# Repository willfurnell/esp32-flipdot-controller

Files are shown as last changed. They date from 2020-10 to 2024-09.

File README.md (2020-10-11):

# `esp32-flipdot-controller`

## Replacement controller for Hannover Flipdot Displays

This is a fork of the original https://github.com/themainframe/esp32-flipdot-controller, but is designed to allow for more than one panel (my display has three), and works with the Platform.IO build, and Arduino ecosystems.

It currently gets the time from an NTP server and displays it. The code obviosuly needs more work, but it's good enough for now. 

Also included in this repository are KiCad schematics for my version of the PCB, which has hardware (but not yet software) support for the built in LED strip and other personal customisations.

Based on the [blog post on damow.net](https://damow.net/fun-with-flip-dot-displays/)!

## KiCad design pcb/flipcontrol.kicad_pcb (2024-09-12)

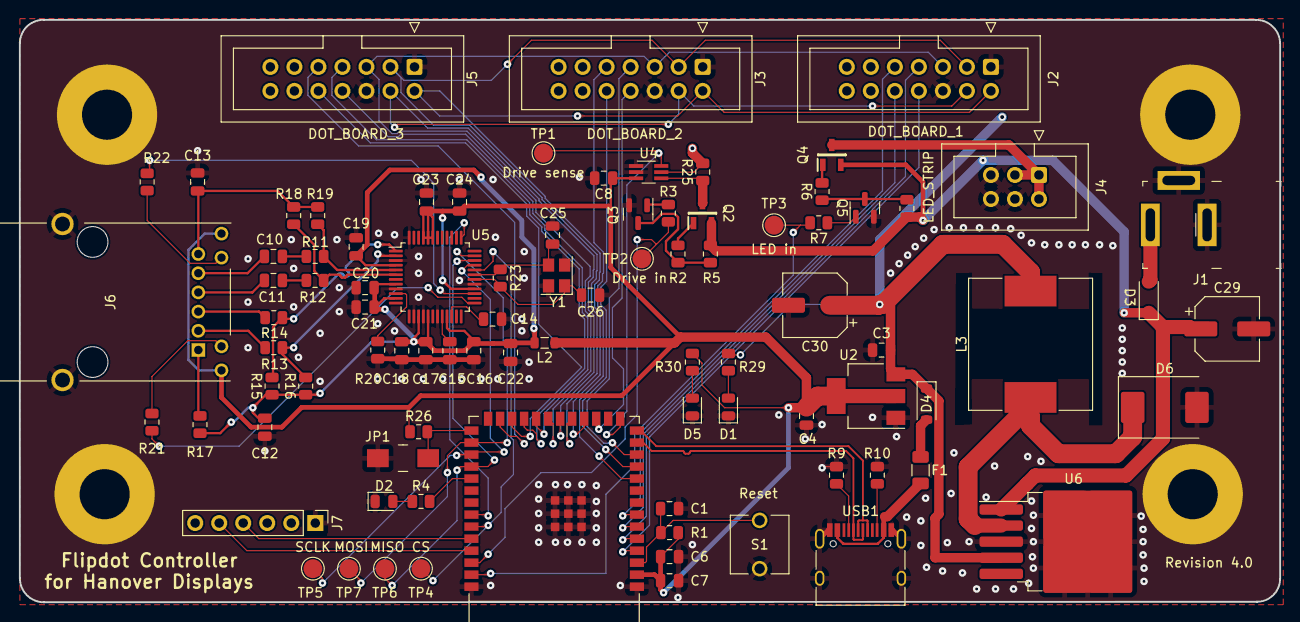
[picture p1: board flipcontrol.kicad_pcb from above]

Board: 4 copper layers, 133.3 x 61.6 mm, 92 parts (0 on the bottom side), 75 nets.

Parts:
C1, C6, C8: 100nF; C_0805_2012Metric
C3, C4, C7, C22, C23: 10uF; C_0805_2012Metric
C10, C11: 6.8nF; C_0805_2012Metric
C12: 22nF; C_0805_2012Metric
C13, C14: 10nF; C_0805_2012Metric
C15: 4.7uF; C_0805_2012Metric
C16, C17, C18, C19, C20, C21, C24: 0.1uF; C_0805_2012Metric
C25, C26: 18pF; C_0805_2012Metric
C29: 100uF; CP_Elec_6.3x5.4
C30: 330uF; CP_Elec_6.3x5.4
D1: 5V; LED_0805_2012Metric
D2: ESP_LED; LED_0805_2012Metric
D3, D4: D; D_SOD-123
D5: 3V3; LED_0805_2012Metric
D6: 700mV 5A; D_SMC
F1: Polyfuse; Fuse_1206_3216Metric
H1, H2, H3, H4: MountingHole_Pad; MountingHole_5.3mm_M5_Pad
J1: PJ-202A; Barrel_Jack_5.5mmODx2.1mmID_PJ-202A
J2: DOT_BOARD_1; IDC-Header_2x07_P2.54mm_Vertical
J3: DOT_BOARD_2; IDC-Header_2x07_P2.54mm_Vertical
J4: LED_STRIP; IDC-Header_2x03_P2.54mm_Vertical
J5: DOT_BOARD_3; IDC-Header_2x07_P2.54mm_Vertical
J6: RJMG163118101NR
J7: FTDI; PinHeader_1x06_P2.54mm_Vertical
JP1: Bootloader; Jumper_Tin_P5.32mm
L2: 120Ohms@100MHz; L_0805_2012Metric
L3: 47uH; L_Sunlord_MWSA1206S-470
Q2, Q4: Si2347DS-T1-GE3; SOT95P237X112-3N
Q3, Q5: MMBT3904; SOT-23
R1, R3, R5, R7, R8, R26: 10K; R_0805_2012Metric
R2, R6: 100R; R_0805_2012Metric
R4: 2K; R_0805_2012Metric
R9, R10: 5.1K; R_0805_2012Metric
R11, R12, R13, R14: 33R; R_0805_2012Metric
R15, R16, R18, R19: 49R9; R_0805_2012Metric
R17: 10R; R_0805_2012Metric
R20: 12.4k; R_0805_2012Metric
R21, R22: 330R; R_0805_2012Metric
R23: 1M; R_0805_2012Metric
R25: 0.015 R; R_0805_2012Metric
R29: 145R; R_0805_2012Metric
R30: 60R; R_0805_2012Metric
S1: RESET; FSM2JRT
TP1: Drive sense; TestPoint_Pad_D2.0mm
TP2: Drive in; TestPoint_Pad_D2.0mm
TP3: LED in; TestPoint_Pad_D2.0mm
TP4: CS; TestPoint_Pad_D2.0mm
TP5: SCLK; TestPoint_Pad_D2.0mm
TP6: MISO; TestPoint_Pad_D2.0mm
TP7: MOSI; TestPoint_Pad_D2.0mm
U2: AMS1117-3.3; SOT-223-3_TabPin2
U3: ESP32-S3-WROOM-1
U4: NCS214; SOT-363_SC-70-6_Handsoldering
U5: W5500; LQFP-48_7x7mm_P0.5mm
U6: LM2596S-5; TO-263-5_TabPin3
USB1: HRO-TYPE-C-31-M-12; USB_C_Receptacle_HRO_TYPE-C-31-M-12
Y1: Crystal_GND24; Crystal_SMD_Abracon_ABM8G-4Pin_3.2x2.5mm

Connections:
+3.3VA: C12.1, C16.1, C17.1, C18.1, C19.1, C20.1, C21.1, C22.1, L2.2, R15.1, R16.1, R17.2, U5.4 (AVDD), U5.8 (AVDD), U5.11 (AVDD), U5.15 (AVDD), U5.17 (AVDD), U5.21 (AVDD)
+3V3: C4.1, C6.2, C7.1, C8.1, C23.1, C24.1, J6.L1 (GREEN_A_1), J6.L4 (GREEN_A_2), L2.1, R1.1, R26.1, R30.1, U2.2 (VO), U3.2 (3V3), U4.3 (Vs), U5.28 (VDD), U5.43 (PMODE2), U5.44 (PMODE1), U5.45 (PMODE0)
+5V: C3.1, C30.1, D4.1 (K), J2.11, J3.11, J5.11, L3.2, R29.1, U2.3 (VI), U6.4 (FB)
+18V: C29.1, D3.1 (K), J2.14, J3.14, J5.14, Q2.2 (S), Q4.2 (S), R5.1, R8.1, U6.1 (VIN)
ACT_LED: R22.2, U5.27 (ACTLED)
COIL_DRIVE_IN: R3.2, TP2.1, U3.38 (GPIO2/TOUCH2/ADC1_CH1)
COIL_DRIVE_OUT: J2.12, J2.13, J3.12, J3.13, J5.12, J5.13, R25.2, U4.5 (-IN)
COIL_DRIVE_SENSE: TP1.1, U3.15 (GPIO3/TOUCH3/ADC1_CH2), U4.6 (OUT)
COL_ADVANCE_1: J2.7, U3.5 (GPIO5/TOUCH5/ADC1_CH4)
COL_ADVANCE_2: J3.7, U3.12 (GPIO8/TOUCH8/ADC1_CH7/SUBSPICS1)
COL_ADVANCE_3: J5.7, U3.23 (GPIO21)
CS: TP4.1, U3.35 (MTMS/GPIO42), U5.32 (~SCS)
EN: C1.1, R1.2, S1.2, U3.3 (EN)
ENABLE_1: J2.2, J3.2, J5.2, U3.18 (GPIO10/TOUCH10/ADC1_CH9/FSPICS0/FSPIIO4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)
ENABLE_2: J2.3, J3.3, J5.3, U3.19 (GPIO11/TOUCH11/ADC2_CH0/FSPID/FSPIIO5/S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)
ENABLE_3: J2.4, J3.4, J5.4, U3.20 (GPIO12/TOUCH12/ADC2_CH1/FSPICLK/FSPIIO6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)
ENABLE_4: J2.5, J3.5, J5.5, U3.21 (GPIO13/TOUCH13/ADC2_CH2/FSPIQ/FSPIIO7/S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)
ESP_LED: R4.2, U3.31 (GPIO38/FSPIWP/SUBSPIWP)
ESP_RXD: J7.4, U3.36 (U0RXD/GPIO44/CLK_OUT2)
ESP_TXD: J7.5, U3.37 (U0TXD/GPIO43/CLK_OUT1)
ETH_RST: U3.34 (MTDI/GPIO41/CLK_OUT1), U5.37 (~RST)
ETH_RXN: R11.1, R19.1, U5.5 (RXN)
ETH_RXP: R12.2, R18.1, U5.6 (RXP)
ETH_TXN: R14.1, R15.2, U5.1 (TXN)
ETH_TXP: R13.1, R16.2, U5.2 (TXP)
GND: C1.2, C3.2, C4.2, C6.1, C7.2, C8.2, C12.2, C13.2, C14.1, C15.1, C16.2, C17.2, C18.2, C19.2, C20.2, C21.2, C22.2, C23.2, C24.2, C25.2, C26.2, C29.2, C30.2, D1.1 (K), D2.1 (K), D5.1 (K), D6.2 (A), H1.1, H2.1, H3.1, H4.1, J1.2, J1.3, J2.1, J2.6, J3.1, J3.6, J4.4, J4.5, J4.6, J5.1, J5.6, J6.S1, J6.S2, J7.1, JP1.1 (A), Q3.2 (E), Q5.2 (E), R9.1, R10.1, R20.2, S1.1, U2.1 (GND), U3.1 (GND), U3.40 (GND), U3.41 (GND), U4.1 (REF), U4.2 (GND), U5.3 (AGND), U5.9 (AGND), U5.14 (AGND), U5.16 (AGND), U5.19 (AGND), U5.29 (GND), U5.48 (AGND), U6.3 (GND), USB1.A1 (GND), USB1.A12 (GND), USB1.B1 (GND), USB1.B12 (GND), USB1.S1 (SHIELD), Y1.2, Y1.4
IO0: JP1.2 (B), R26.2, U3.27 (GPIO0/BOOT)
LED_IN: R7.2, TP3.1, U3.39 (GPIO1/TOUCH1/ADC1_CH0)
LED_OUT: J4.1, J4.2, J4.3, Q4.3 (D)
LINK_LED: R21.2, U5.25 (LINKLED)
MISO: TP6.1, U3.30 (SPIDQS/GPIO37/FSPIQ/SUBSPIQ), U5.34 (MISO)
MOSI: TP7.1, U3.28 (SPIIO6/GPIO35/FSPID/SUBSPID), U5.35 (MOSI)
unnamed: C10.2, R11.2
unnamed: C11.1, R12.1
unnamed: D1.2 (A), R29.2
unnamed: D2.2 (A), R4.1
unnamed: D3.2 (A), J1.1
unnamed: D4.2 (A), F1.2
unnamed: D5.2 (A), R30.2
unnamed: D6.1 (K), L3.1, U6.2 (OUT)
unnamed: J6.L2 (GREEN_K_1), R21.1
unnamed: J6.L3 (GREEN_K_2), R22.1
unnamed: C13.1, J6.R6 (RCT), R18.2, R19.2
unnamed: C11.2, J6.R4 (RX+)
unnamed: C10.1, J6.R5 (RX-)
unnamed: J6.R1 (TCT), R17.1
unnamed: J6.R2 (TX+), R13.2
unnamed: J6.R3 (TX-), R14.2
unnamed: Q2.3 (D), R25.1, U4.4 (+IN)
unnamed: Q2.1 (G), R2.2
unnamed: Q3.1 (B), R3.1
unnamed: Q3.3 (C), R2.1, R5.2
unnamed: Q4.1 (G), R6.2
unnamed: Q5.1 (B), R7.1
unnamed: Q5.3 (C), R6.1, R8.2
unnamed: C14.2, U5.22 (1V2O)
unnamed: R20.1, U5.10 (EXRES1)
unnamed: C15.2, U5.20 (TOCAP)
unnamed: C26.1, R23.2, U5.30 (XI/CLKIN), Y1.1
unnamed: C25.1, R23.1, U5.31 (XO), Y1.3
unnamed: R9.2, USB1.A5 (CC1)
unnamed: R10.2, USB1.B5 (CC2)
RESET_1: J2.8, U3.4 (GPIO4/TOUCH4/ADC1_CH3)
RESET_2: J3.8, U3.17 (GPIO9/TOUCH9/ADC1_CH8/FSPIHD/SUBSPIHD)
RESET_3: J5.8, U3.22 (GPIO14/TOUCH14/ADC2_CH3/FSPIWP/FSPIDQS/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)
ROW_ADVANCE_1: J2.10, U3.6 (GPIO6/TOUCH6/ADC1_CH5)
ROW_ADVANCE_2: J3.10, U3.11 (GPIO18/U1RXD/ADC2_CH7/CLK_OUT3)
ROW_ADVANCE_3: J5.10, U3.24 (GPIO47/SPICLK_P/SUBSPICLK_P_DIFF)
SCLK: TP5.1, U3.29 (SPIIO7/GPIO36/FSPICLK/SUBSPICLK), U5.33 (SCLK)
SET_UNSET_1: J2.9, U3.7 (GPIO7/TOUCH7/ADC1_CH6)
SET_UNSET_2: J3.9, U3.10 (GPIO17/U1TXD/ADC2_CH6)
SET_UNSET_3: J5.9, U3.25 (GPIO48/SPICLK_N/SUBSPICLK_N_DIFF)
USB_DN: U3.13 (GPIO19/U1RTS/ADC2_CH8/CLK_OUT2/USB_D-), USB1.A7 (D-), USB1.B7 (D-)
USB_DP: U3.14 (GPIO20/U1CTS/ADC2_CH9/CLK_OUT1/USB_D+), USB1.A6 (D+), USB1.B6 (D+)
USB_VBUS: F1.1, USB1.A4 (VBUS), USB1.A9 (VBUS), USB1.B4 (VBUS), USB1.B9 (VBUS)

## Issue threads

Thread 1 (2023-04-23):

Drive current measurement

russss, 2023-04-23:
During initialisation, the original Hanover controller detects the size of display by flipping dots along a row and a column and (presumably) measuring the drive current to detect where the display ends.

Replicating this is a bit frivolous - you could just store the size of the display in flash - but it's kind of cool and I'd like to try and emulate it.

(I wonder if this might actually provide a way of speeding up refresh rates, if you could use the current draw to detect when the dot has been flipped?)

I think this just needs a current shunt resistor in the drive line, and then an op-amp (which can be optional) and an ADC channel.

Closed 2023-05-11.

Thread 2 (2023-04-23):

Ethernet support

russss, 2023-04-23:
I'd like wired ethernet support for using these displays at events. I'm a bit wary of using wifi especially when the ESP32 is in a metal box.

If we're using the ESP32-S3 then it sounds like we need an SPI MAC/PHY for this. The throughput should be pretty minimal so hopefully this won't be an issue.

All the ethernet stuff should be optional.

willfurnell, 2023-05-06:
I have added this to the schematic

Closed 2023-05-11.

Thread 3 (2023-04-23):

LED strip driving thoughts

russss, 2023-04-23:
Two things:

1) I have a suspicion that these flipdots would look pretty good under UV lighting. Maybe we should have provision for driving multiple independent channels of LED so that I can fit a combined white and UV strip and pick a colour.

2) Is the stock Hanover LED strip driven at 18V or 24V? 24V is a standard voltage for non-addressable LED strip, so if we retrofit strip it's going to be under-driven at 18V. Some of the LEDs in our signs are looking a bit crap and could do with replacement, so this doesn't solely affect my UV plans. We should check the voltage of the stock Hanover strip, and if it's 18V we should check how well 24V strip performs at that voltage.

russss, 2023-04-28:
The plot thickens, I've just checked the LED voltage in our smallest flipdot and it's running at 16V...

willfurnell, 2023-05-06:
As per discussion on Slack - 16V is a pain - probably going to ignore the LED strips on the first revision. Why would they do this...?!

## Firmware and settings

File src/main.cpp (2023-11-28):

#include <stdlib.h>
#include <stdint.h>
#include <unistd.h>
#include <string.h>
#include "esp_log.h"
#include "WiFi.h"
#include "flipdot.h"
#include "fill.h"
#include "main.h"
#include "scroll.h"
#include "text.h"
#include <WiFiUdp.h>
#include "NTP.h"
#include <ESPmDNS.h>
#include "graphics.h"

static const char *TAG = "Main";

const char *ssid = "NoConnection";
const char *password = "";
const char *host = "flipdot";

WiFiUDP ntpUDP;
NTP ntp(ntpUDP);

dotboard_t dots;

void setup()
{
    ESP_LOGI(TAG, "Flipdot Display Controller System startup");

    // Initialise display
    flipdot_init();

    fill_on(&dots);
    write_dotboard(&dots, true);
    fill_off(&dots);
    write_dotboard(&dots, true);
    render_text_4x5(&dots, 0, 1, "Connecting...");
    write_dotboard(&dots, true);

    // Init wifi

    WiFi.begin(ssid, password);

    while (WiFi.status() != WL_CONNECTED)
    {
        vTaskDelay(500 / portTICK_RATE_MS);
    }

    if (!MDNS.begin(host))
    {
        ESP_LOGE("Error setting up MDNS responder!");
        while (1)
        {
            vTaskDelay(1000 / portTICK_RATE_MS);
        }
    }
    fill_off(&dots);
    render_text_4x5(&dots, 0, 1, WiFi.localIP().toString().c_str());
    write_dotboard(&dots, true);
    vTaskDelay(2000 / portTICK_RATE_MS);

    //fill_off(&dots);
    //write_dotboard(&dots, true);

    // Set up summer time rules
    ntp.ruleDST("BST", Last, Sun, Mar, 1, 60);
    ntp.ruleSTD("GMT", Last, Sun, Oct, 2, 0);
    ntp.begin();

    fill_off(&dots);
    render_text_4x5(&dots, 0, 1, ntp.formattedTime("%a %d %b %H:%M"));
    write_dotboard(&dots, true);
}

void loop()
{
    ntp.update();
    //fill_on(&dots);
    //fill_off(&dots);
    //render_text_4x5(&dots, 0, 1, "PARTAYYYYYYYYY");
    //write_dotboard(&dots, false);
    //vTaskDelay(10000 / portTICK_RATE_MS);
    //fill_off(&dots);
    //render_text_4x5(&dots, 0, 1, "HAPPY BIRTHDAY!");
    //write_dotboard(&dots, false);
    //vTaskDelay(10000 / portTICK_RATE_MS);
    //fill_off(&dots);
    //render_text_4x5(&dots, 0, 1, "LAURA AND MEGAN");
    //write_dotboard(&dots, false);
    //vTaskDelay(10000 / portTICK_RATE_MS);
    fill_off(&dots);
    render_text_4x5(&dots, 0, 1, ntp.formattedTime("%a %d %b %H:%M"));
    write_dotboard(&dots, false);
    //scroll_update();
    vTaskDelay(20000 / portTICK_RATE_MS);
    fill_off(&dots);
    render_cyberman(&dots, 0);
    render_cyberman(&dots, 9);
    render_cyberman(&dots, 18);
    render_cyberman(&dots, 27);
    render_cyberman(&dots, 36);
    render_cyberman(&dots, 45);
    render_cyberman(&dots, 54);
    render_cyberman(&dots, 63);
    render_cyberman(&dots, 72);
    render_cyberman(&dots, 72);
    write_dotboard(&dots, false);
    vTaskDelay(20000 / portTICK_RATE_MS);
    //render_text_4x5(&dots, 0, 1, "HAPPY BIRTHDAY!");
    //write_dotboard(&dots, false);
    //vTaskDelay(10000 / portTICK_RATE_MS);
    //fill_off(&dots);
    //render_text_4x5(&dots, 0, 1, "MEGAN AND LAURA");
    //write_dotboard(&dots, false);
    //vTaskDelay(10000 / portTICK_RATE_MS);
    //fill_off(&dots);
    //render_text_4x5(&dots, 0, 1, ntp.formattedTime("%a %d %b %H:%M"));
    //write_dotboard(&dots, false);
    //scroll_update();
}

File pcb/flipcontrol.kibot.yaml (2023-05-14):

kibot:
  version: 1

global:
  filters:
  - number: 1007
  - number: 1015
  - number: 58

import:
- file: Elecrow
- file: FusionPCB
- file: JLCPCB
- file: MacroFab_XYRS
- file: PCB2Blender_2_1
- file: PCBWay

outputs:
- name: basic_blender_export
  comment: 3D view from top/30 deg/bottom (Blender)
  type: blender_export
  dir: 3D
  options:
    pcb3d: _PCB2Blender_2_1
    outputs:
    - type: render
    - type: blender
    point_of_view:
    - view: top
    - rotate_x: 30
      rotate_z: -20
      file_id: _30deg
    - view: bottom
- name: basic_boardview
  comment: Board View export
  type: boardview
  dir: Assembly
- name: generic_bom_html
  comment: Generic Bill of Materials in HTML format
  type: bom
  dir: BoM/Generic
  options:
    format: HTML
    group_fields: &id001
    - part
    - part lib
    - value
    - footprint
    - footprint lib
    - voltage
    - tolerance
    - current
    - power
    - mpn
    count_smd_tht: true
- name: generic_bom_csv
  comment: Generic Bill of Materials in CSV format
  type: bom
  dir: BoM/Generic
  options:
    format: CSV
    group_fields: *id001
    count_smd_tht: true
- name: generic_bom_hrtxt
  comment: Generic Bill of Materials in HRTXT format
  type: bom
  dir: BoM/Generic
  options:
    format: HRTXT
    hrtxt:
      separator: '|'
    group_fields: *id001
    count_smd_tht: true
- name: generic_bom_tsv
  comment: Generic Bill of Materials in TSV format
  type: bom
  dir: BoM/Generic
  options:
    format: TSV
    group_fields: *id001
    count_smd_tht: true
- name: generic_bom_xml
  comment: Generic Bill of Materials in XML format
  type: bom
  dir: BoM/Generic
  options:
    format: XML
    group_fields: *id001
    count_smd_tht: true
- name: generic_bom_xlsx
  comment: Generic Bill of Materials in XLSX format
  type: bom
  dir: BoM/Generic
  options:
    format: XLSX
    group_fields: *id001
    count_smd_tht: true
- name: positional_bom_html
  comment: Positional Bill of Materials in HTML format
  type: bom
  dir: BoM/Positional
  options:
    format: HTML
    group_fields: *id001
    columns: &id002
    - Row
    - Description
    - Part
    - Part Lib
    - References
    - Value
    - Footprint
    - Footprint Lib
    - Quantity Per PCB
    - Build Quantity
    - Status
    - Datasheet
    - Sheetpath
    - Source BoM
    - Footprint X
    - Footprint Y
    - Footprint Rot
    - Footprint Side
    - Footprint Type
    - Footprint Populate
    - Footprint X-Size
    - Footprint Y-Size
    count_smd_tht: true
    html:
      style: modern-red
- name: positional_bom_xlsx
  comment: Positional Bill of Materials in XLSX format
  type: bom
  dir: BoM/Positional
  options:
    format: XLSX
    group_fields: *id001
    columns: *id002
    count_smd_tht: true
    xlsx:
      style: modern-red
- name: costs_bom_xlsx
  comment: Costs Bill of Materials in XLSX format
  type: bom
  dir: BoM/Costs
  options:
    format: XLSX
    group_fields:
    - part
    - part lib
    - value
    - footprint
    - footprint lib
    - voltage
    - tolerance
    - current
    - power
    - manf#
    count_smd_tht: true
    xlsx:
      style: modern-green
      kicost: true
      specs: true
      kicost_api_disable: KitSpace
    pre_transform: _kicost_rename
- name: basic_download_datasheets
  comment: Download the datasheets
  type: download_datasheets
  dir: Datasheets
- name: basic_dxf
  comment: Individual layers in DXF format
  type: dxf
  dir: Individual_Layers/DXF
  layers:
  - layer: F.Cu
    suffix: F_Cu
    description: Front copper
  - layer: In1.Cu
    suffix: In1_Cu
    description: Inner layer 1
  - layer: In2.Cu
    suffix: In2_Cu
    description: Inner layer 2
  - layer: B.Cu
    suffix: B_Cu
    description: Bottom copper
  - layer: F.Paste
    suffix: F_Paste
    description: Front solder paste
  - layer: B.Silkscreen
    suffix: B_Silkscreen
    description: Bottom silkscreen (artwork)
  - layer: F.Silkscreen
    suffix: F_Silkscreen
    description: Front silkscreen (artwork)
  - layer: B.Mask
    suffix: B_Mask
    description: Bottom soldermask (negative)
  - layer: F.Mask
    suffix: F_Mask
    description: Front soldermask (negative)
  - layer: User.Comments
    suffix: User_Comments
    description: User comments
  - layer: User.Eco2
    suffix: User_Eco2
    description: For user usage 2
  - layer: Edge.Cuts
    suffix: Edge_Cuts
    description: Board shape
  - layer: F.Courtyard
    suffix: F_Courtyard
    description: Front courtyard area
  - layer: F.Fab
    suffix: F_Fab
    description: Front documentation
- name: Elecrow_gerbers
  comment: Gerbers compatible with Elecrow
  type: gerber
  dir: Manufacturers/Elecrow
  extends: _Elecrow_gerbers
  disable_run_by_default: true
  layers: &id003
  - layer: F.Cu
    suffix: F_Cu
    description: Front copper
  - layer: In1.Cu
    suffix: In1_Cu
    description: Inner layer 1
  - layer: In2.Cu
    suffix: In2_Cu
    description: Inner layer 2
  - layer: B.Cu
    suffix: B_Cu
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

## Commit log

2020-10-11 Convert to platform.io
    [BoardOutline.gbr, Bottom.gbr, BottomAssy.gbr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]
2020-10-11 Update to work with more than one panel (in this case three)
2020-10-11 Add PCB files
    [flipcontrol-B.Cu.gbr, flipcontrol-B.Mask.gbr, flipcontrol-B.Paste.gbr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]
2023-04-21 Update for Kicad 7, update some components
    [flipcontrol.kicad_pcb, flipcontrol.kicad_sch]
2023-04-22 Update schematic with newer parts
    [flipcontrol.kicad_sch]
2023-04-22 Update PCB
    [flipcontrol.csv, flipcontrol.kicad_pcb, flipcontrol.kicad_sch]
2023-04-23 Update with latest schematic and board changes
    [flipcontrol.kicad_pcb, flipcontrol.kicad_sch]
2023-04-23 Update .gitignore with new KiCad bits
2023-04-23 Add required kicad parts straight into this repo
2023-04-23 Start work on Ethernet support in schematic
    [flipcontrol.kicad_sch]
2023-04-25 Finish adding Ethernet interface
    [flipcontrol.kicad_sch]
2023-04-29 Remove old KiCAD v6 project files
    [flipcontrol.sch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]
2023-05-06 Add footprints for all parts
    [flipcontrol.kicad_sch]
2023-05-07 Schematic update
    * Remove USB-serial chip, use ESP32's USB support
    * Add serial header and bootloader jumper in case that doesn't work
    * Add drive current sensing
    * ERC tidyup
    * Add a few test points for good measure
    [flipcontrol.kicad_sch]
2023-05-08 Rework schematic:
    New 5V regulator design, use ESP32's native USB and add FTDI header,
    misc other improvements
    [flipcontrol.kicad_sch]
2023-05-08 PCB layout
    [flipcontrol.kicad_pcb, flipcontrol.kicad_sch]
2023-05-08 Fix board being ever so slightly off square
    [flipcontrol.kicad_pcb]
2023-05-08 Remove gerbers folder
    [flipcontrol-B.Cu.gbr, flipcontrol-B.Mask.gbr, flipcontrol-B.Paste.gbr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]
2023-05-11 Make panel pin 14 constantly powered with 18V
    [flipcontrol.kicad_pcb, flipcontrol.kicad_sch]
2023-05-14 Remove broken kibot targets, remove BOM file
    [flipcontrol.csv]
2023-05-14 Schematic updates to improve component values
    [flipcontrol.kicad_sch]
2023-11-28 Update PCB to use more JLCPCB parts for power supply
    [flipcontrol.kicad_pcb]
2024-02-04 Properly deal with multi panel boards
2024-02-04 Add new env for rev3 boards
2024-09-12 Rev4: Make more parts JLCPCB assembly service compatible
    [flipcontrol.kicad_pcb, flipcontrol.kicad_sch]
